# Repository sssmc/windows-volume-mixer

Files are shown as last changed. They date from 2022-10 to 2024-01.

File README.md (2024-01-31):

# Windows Volume Mixer

A physical hardware interface for adjusting main and per-app volumes in windows.



### Hardware

All hardware is presented in a desktop unit mounted at an angle for ergonomic use. The mixer consists of four channels. Each channel has a small screen for displaying the name of the channel, a rotary encoder knob for controlling the volume of that channel and ring of RGB LEDs around the knob to display the volume level of the channel. Below the knobs is a bank of key switches that can control aspects of the mixer as well other functions in windows. The mixer is connected to the windows PC via a USB-C cable for power and communications.

I2C is used for the screens, encoders, and buttons. All devices are connected to the microcontroller via cables and connectors, resulting minimal soldering needed for the construction. Once the initial soldering is completed, the whole unit can be assembled and disassembled with no soldering needed.
The enclosure for the electronics is 3D-printable on consumer printer and uses minimal M2/M3 hardware for assembly.

### Software

The software for the mixer consists of two main parts: firmware running on the microcontroller and a python script running on the PC. The two programs communicate via serial over a USB cable. The firmware reads the values of the rotary encoders and the various buttons and reports them when they change to the PC over serial. The python scripts then process these values, set appropriate volumes on the PC, decides what apps will be assigned to what channels etc. The script then sends values to be displayed on the screens and the LED rings back to the microcontroller.

The python script uses the Pycaw library to access the windows APIs to get and change app specific volumes.

## Current State of the Project and Development Plans

The project is a working, but early state. The software especially has some instability and many features to be implemented.

### Hardware

The electronics are mostly final state. Since the components were chosen to facilitate fast prototyping, the overall cost of them was fairly high. This could be improved by incorporating more custom built parts or moving most components to a single custom PCB. However, this would be impractical outside larger scale production so therefore unlikely in the near future for this project.

The current 3D-printed enclosure consists of a solid faceplate mounted on an open frame. A fully enclosed design could add more polish to the project.

### Software

Software/firmware is where most of the remaining work is to be done on the project. The firmware on the microcontroller is fairly complete and has no know bugs at this time. The python script running on the pc has a few know issues and quite a few features to be implemented.

#### Know issues:
<ul>
    <li>Intermittent crashes when switching audio outputs in windows.</li>
    <li>Intermittent loss of master volume control.</li>
    <li>Random script crashes.</li>
</ul>

#### Missing features:
<ul>
    <li>When volumes or mutes are changed in windows, update mixer automatically.</li>
    <li>When output source is changed in windows, update mixer automatically.</li>
    <li>Display more info about channels on screens.</li>
    <li>Add more functions to buttons, including changing audio output sources.</li>
    <li>Add more user feedback using button backlights.</li>
    <li>Run python script in background(in task bar).</li>
    <li>Add GUI to view connection status and adjust settings.</li>
</ul>

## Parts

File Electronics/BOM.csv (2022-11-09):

Part Name | Part No. | Manufacturer | Quantity | Source | Notes
0.96in I2C 128x64 OLED | Various | Various | 4 | https://www.aliexpress.com/item/32638662748.html
NeoPixel Ring - 16 x 5050 RGB LED | 1463 | Adafruit | 4 | https://www.adafruit.com/product/1463
Adafruit I2C Stemma QT Rotary Encoder Breakout | 4991 | Adafruit | 4 | https://www.adafruit.com/product/4991
NeoKey 1x4 QT I2C - Four Mechanical Key Switches | 4980 | Adafruit | 2 | https://www.adafruit.com/product/4980
Adafruit Feather RP2040 | 4884 | Adafruit | 1 | https://www.adafruit.com/product/4884
FeatherWing Proto | 2884 | Adafruit | 1 | https://www.adafruit.com/product/2884
Stacking Headers for Feather | 2830 | Adafruit | 1 | https://www.adafruit.com/product/2830
Cherry MX Compatiable Keyswitch | Various | Various | 8 | Various
Cherry MX Compatiable Keycap | Various | Various | 8 | Various
Qwiic/Stemma QT Cable - 50mm | Various | Various | 4 | Various
Qwiic/Stemma QT Cable - 100mm | Various | Various | 2 | Various
Qwiic Cable - Female Jumper (4-pin) | Various | Various | 1 | Various | Modified to add a second set of female headers(to connected to 2 OLEDs)
JST PH 2mm 4-Pin to Female Socket Cable - 200mm | 3950 | Adafruit | 1 | Various | Modified to add a second set of female headers(to connected to 2 OLEDs)
JST PH 4-Pin Socket | Various | Various | 1 | Various
JST PH 3-Pin Socket | Various | Various | 4 | Various
JSP PH 3-Pin Connector | Various | Various | 4 | Various
Single Female Header Jumper | Various | Various | 8 | Various | For OLED cable modifications
Misc. Hookup Wire | Various | Various |  | Various | For cable modifications and connections on feather wing proto
Misc. M3/M2 Machine Screws | Various | Various |  | Various

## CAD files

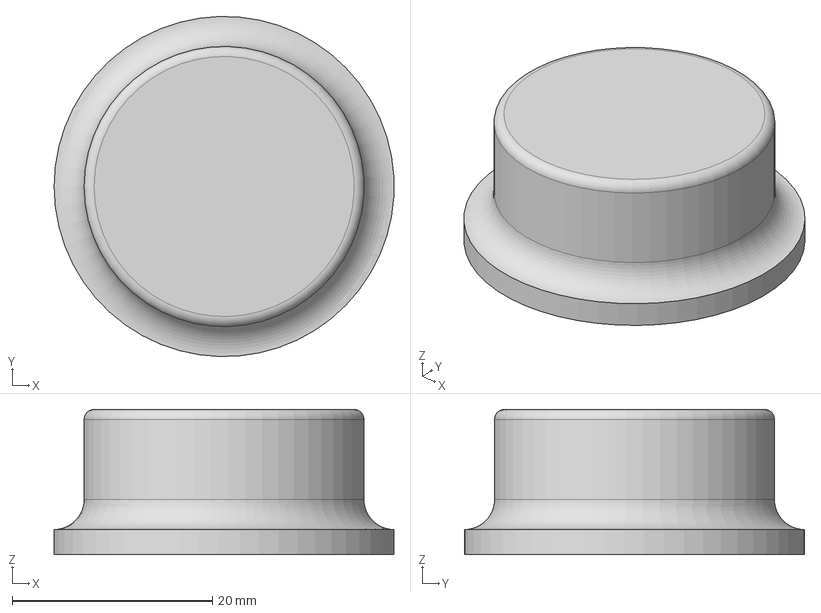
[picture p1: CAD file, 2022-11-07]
3D Models/Knob/Knob V1.step
34.0 x 34.0 x 14.5 mm

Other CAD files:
3D Models/Knob/Knob_V1.f3d
3D Models/Knob/Knob_V1.stl

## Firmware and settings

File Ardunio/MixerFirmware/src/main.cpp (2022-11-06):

#include <Arduino.h>

#include "Adafruit_NeoKey_1x4.h"
#include "seesaw_neopixel.h"
#include <Adafruit_NeoPixel.h>

#include <Adafruit_GFX.h>
#include <Adafruit_SSD1306.h>

//Pins for encoder seesaw chip
#define SS_SWITCH        24
#define SS_NEOPIX        6

//Max brightness for the neopixel rings
#define RING_BRIGHTNESS 25.5

//OLED screens
#define SCREEN_WIDTH 128 // OLED display width, in pixels
#define SCREEN_HEIGHT 32 // OLED display height, in pixels
#define OLED_RESET     -1 // Reset pin # (or -1 if sharing Arduino reset pin)

//I2C Buses and pins(Wire1 = Stemma Qt connector, Wire = feather wing)
#define WIRE Wire
#define WIRE1 Wire1
#define WIRE_SDA 8
#define WIRE_SCL 9
#define WIRE1_SDA 2
#define WIRE1_SCL 3

//Serial Baud Rate
#define SERIAL_BAUD_RATE 4000000

#define SLEEP_DELAY 6000

int inputCount = 0;

//I2C addresses
int rotary_addrs[4] = {0x36, 0x37, 0x3A, 0x38};
int key_addrs[2] = {0x30, 0x31};
int display_addrs[4] = {0x3C, 0x3D, 0x3C, 0x3D};

//Order to turn on the pixels in the neopixel rings
int ring_pixel_order[16] = {5, 4, 3, 2, 1, 0, 15, 14, 13, 12, 11, 10, 9, 8, 7, 6};

//input data from the serial bus(20 char arrays, max 255 chars each)
char inData[20][255];

//OLED display objects
Adafruit_SSD1306 displays[] = {
  Adafruit_SSD1306(SCREEN_WIDTH, SCREEN_HEIGHT, &Wire1, OLED_RESET),
  Adafruit_SSD1306(SCREEN_WIDTH, SCREEN_HEIGHT, &Wire1, OLED_RESET),
  Adafruit_SSD1306(SCREEN_WIDTH, SCREEN_HEIGHT, &Wire, OLED_RESET),
  Adafruit_SSD1306(SCREEN_WIDTH, SCREEN_HEIGHT, &Wire, OLED_RESET)
};

//Neo Key objects
Adafruit_NeoKey_1x4 keys[] = {
  Adafruit_NeoKey_1x4('0', &Wire1),
  Adafruit_NeoKey_1x4('0', &Wire1),
};

//Encoder objects
Adafruit_seesaw encoders[4] = {
  Adafruit_seesaw(&Wire1),
  Adafruit_seesaw(&Wire1),
  Adafruit_seesaw(&Wire1),
  Adafruit_seesaw(&Wire1)
};

//Neopixel ring objects(with pins)
Adafruit_NeoPixel rings[4] = {
  Adafruit_NeoPixel(16, A0, NEO_GRB + NEO_KHZ800),
  Adafruit_NeoPixel(16, A1, NEO_GRB + NEO_KHZ800),
  Adafruit_NeoPixel(16, A2, NEO_GRB + NEO_KHZ800),
  Adafruit_NeoPixel(16, A3, NEO_GRB + NEO_KHZ800)
};

//Encoder postion vars
int32_t encoder_positions[] = {0, 0, 0, 0};
int32_t encoder_last_positions[] = {0, 0, 0, 0};
int32_t encoder_position_changes[] = {0, 0, 0, 0};

//Encoder button vars
bool encoder_button_states[] = {false, false, false, false};
bool encoder_button_last_states[] = {false, false, false, false};

//Neokey button state vars
bool button_states[] = {false, false, false, false, false, false, false, false};
bool button_last_states[] = {false, false, false, false, false, false, false, false};

//Colors of the neokey button backlights(hex)
int buttonColors[8] = {0x0000FF, 0x0000FF, 0x0000FF, 0x0000FF, 0x0000FF, 0x0000FF, 0x0000FF, 0x0000FF};

//Neopixel ring levels(0-16)
int ring_levels[4] = {0, 0, 0, 0};

//Color of the neopixel rings(hex)
int ringColors[4] = {0xFF8000, 0xFF8000, 0xFF8000, 0xFF8000};

//No connection neopixel ring color
int NO_CONNECT_COLOR = 0x0000FF;

//No connection display text
String NO_CONNECTION_TEXT = "No Connection";

//OLED display texts
char appNames[4][255];

//Is it the first time going thorugh the loop since the serial was connected
bool serialFirstTime = true;

//Sleep Timer
unsigned long sleepTimerStart = 0;


//--Function Prototypes--//

//Write the data to serial
//Formate: [(encoder positon changes)x4, (neokey button states)x8, (encoder button states)x4]
void serialWrite();

//Read data from serial
void serialRead();

//Get the neokey button states and update the neopixle backlight colors
void getKeys();

//Get encoder position and button data
void getEncoders();

//Set the level and color of the neopixel rings
void setRings();

//Set the text for the OLED displays
void setDisplays();

//Set neopixel rings to the no connection color and set a no connection message on the first screen
//Option so clear all displays
void setNoConnection(bool clearDisplay);

//Puts device in sleep mode
void setSleep();


void setup() {

  //Setup and start the I2C busses
  WIRE.setSDA(WIRE_SDA);
  WIRE.setSCL(WIRE_SCL);
  WIRE.begin();

  WIRE1.setSDA(WIRE1_SDA);
  WIRE1.setSCL(WIRE1_SCL);
  WIRE1.begin();

  //Start the OLED displays
  for (int i = 0; i < 4; i++) {
    if (!displays[i].begin(SSD1306_SWITCHCAPVCC, display_addrs[i])) {
      for (;;); // Can't start display, don't proceed, loop forever
    }
    displays[i].display();//Show the default splash screen
  }

  //Start the neokeys
  for (int i = 0; i < 2; i ++) {
    if (! keys[i].begin(key_addrs[i])) {
      while (1) delay(10);
    }
  }
  
  //Start the endoders
  for (int i = 0; i < 4; i++) {

    Adafruit_seesaw ss = encoders[i];

    if (! ss.begin(rotary_addrs[i])) {
      while (1) delay(10); //Can't start, loop forever
    }
    uint32_t version = ((ss.getVersion() >> 16) & 0xFFFF);
    if (version  != 4991) {
      while (1) delay(10); //Incorrect seesaw firware version, loop forever
    }
    encoders[i] = ss;

    //Set intial positions for the encoders
    encoder_positions[i] = encoders[i].getEncoderPosition();
    encoder_button_states[i] = encoders[i].digitalRead(SS_SWITCH);
    encoder_button_last_states[i] = encoders[i].digitalRead(SS_SWITCH);
  }

  //Start the neopixel rings
  for (int i = 0; i < 4; i++) {
    rings[i].begin();

    //Set max brightness
    rings[i].setBrightness(RING_BRIGHTNESS);
  }

  //Show a no connection message on the first screen and set rings to no connection color
  setNoConnection(false);

  //Start the serial connection and wait until the pc connect before proceding
  Serial.begin(SERIAL_BAUD_RATE);

  sleepTimerStart = millis();

}

void loop() {
  
  //If the pc is connected to the serial

  //Neokeys
  getKeys();

  //Encoders
  getEncoders();
  if (Serial) {
    //If there is the first loop since the serial was connected, sent data to get a respose from the pc
    if (serialFirstTime) {
      serialWrite();
      serialFirstTime = false;
    }

    sleepTimerStart = millis();//Restart sleep timer(since the device does not sleep when connected to serial)

    //While they are bytes in the serial buffer, read data and set rings/displays
    while (Serial.available() > 0) {

        serialRead();
    }

  }else
  {
    //If there is no serial connection, set ring and displays to no connection state

    serialFirstTime = true;

    //If the sleep timer triggers(the serial connection has been lost for the sleep delay or more)
    if((millis() - sleepTimerStart) > SLEEP_DELAY){

      setSleep();

    } else{
      setNoConnection(true);
    }

  }
}

void serialWrite() {
  sleepTimerStart = millis();//Restart sleep timer(since a user changed an input)
  if(Serial){
    Serial.print("[");

    for (int i = 0; i < 4; i++) {
      Serial.print(encoder_position_changes[i]);
      Serial.print(",");
    }

    for (int i = 0; i < 8; i++) {
      Serial.print(button_states[i]);
      Serial.print(",");
    };
    for (int i = 0; i < 4; i++) {
      Serial.print(!encoder_button_states[i]);
      Serial.print(",");
    }
    Serial.println("]");
  }
}

void getKeys(){
  for (int i = 0; i < 2; i++) {
      Adafruit_NeoKey_1x4 neokey = keys[i];
      uint8_t buttons = neokey.read();

      // Check each button. Ff the state has changed since last check, write to serial
      if (buttons & (1 << 0)) {
        if (!button_states[4 * i]) {
          button_states[4 * i] = true;
          serialWrite();
        }
      } else {
        if (button_states[4 * i]) {
          button_states[4 * i] = false;
          serialWrite();
        }
      }
      if (buttons & (1 << 1)) {
        if (!button_states[(4 * i) + 1]) {
          button_states[(4 * i) + 1] = true;
          serialWrite();
        }
      } else {
        if (button_states[(4 * i) + 1]) {
          button_states[(4 * i) + 1] = false;
          serialWrite();
        }
      }
      if (buttons & (1 << 2)) {
        if (!button_states[(4 * i) + 2]) {
          button_states[(4 * i) + 2] = true;
          serialWrite();
        }
      } else {
        if (button_states[(4 * i) + 2]) {
          button_states[(4 * i) + 2] = false;
          serialWrite();
        }
      }
      if (buttons & (1 << 3)) {
        if (!button_states[(4 * i) + 3]) {
          button_states[(4 * i) + 3] = true;
          serialWrite();
        }
      } else {
        if (button_states[(4 * i) + 3]) {
          button_states[(4 * i) + 3] = false;
          serialWrite();
        }
      }
      //Set the button backlight neopixel colors
      for(int b = 0;b < 4; b++){
        neokey.pixels.setPixelColor(b, buttonColors[(4 * i) + b]);
      }
      neokey.pixels.show();
    }
}

void getEncoders(){
  for (int i = 0; i < 4; i++) {
      //Get encoder positons and button states
      encoder_positions[i] = encoders[i].getEncoderPosition();
      encoder_button_states[i] = encoders[i].digitalRead(SS_SWITCH);

      //If the encoder positon has chages since the last check, calculate the position diffrence since last check and write to serial
      if (encoder_positions[i] != encoder_last_positions[i]) {
        encoder_position_changes[i] = encoder_positions[i] - encoder_last_positions[i];
        serialWrite();
        //Reset last position
        encoder_last_positions[i] = encoder_positions[i];
      } else {
        //If there has been no change, set position difference to 0
        encoder_position_changes[i] = 0;
      }

      //If the encoder button has changed since last check, update state and write to serial
      if (encoder_button_states[i] != encoder_button_last_states[i]) {
        serialWrite();
        encoder_button_last_states[i] = encoder_button_states[i];
      }
    }
}

void setDisplays(){

  //Set each display to its app name
  for (int i = 0; i < 4; i ++) {
    displays[i].clearDisplay();
    displays[i].setTextSize(2);
    displays[i].setTextColor(SSD1306_WHITE);
    displays[i].setCursor(0, 0);
    displays[i].println(String(appNames[i]));
    displays[i].display();
  }

}

void setRings(){

  for (int i = 0; i < 4; i++)
    {
      //Clear the ring
      rings[i].clear();

      //Set the number of pixels lit on the ring base on the ring level(0-16)
      for (int r = 0; r < ring_levels[i]; r++) {
        //Use the the custom pixel order to choose the order that the pixels are turned on
        //Use the ring color of that ring to dertimin the color
        rings[i].setPixelColor(ring_pixel_order[r], ringColors[i]);
      }
      //Show the pixels
      rings[i].show();
    }

}

void serialRead(){

  sleepTimerStart = millis();

  //Read string until a comma is reached(end of value), String is then converted into char array and added to in data array
  Serial.readStringUntil(',').toCharArray(inData[inputCount], 255);

  //Keep track of how many values have been read on the current line
  inputCount ++;

  //If we have reached the end of the line(empty string caused by the ",," at the end of the line), process line
  if (String(inData[inputCount - 1]) == "") {

    //Reset line value count
    inputCount = 0;
    int displayCount = 0;

    //Read ring and button colors(as ints)
    for (int i = 0; i < 4; i++) {
      ringColors[i] = String(inData[i + 8]).toInt();
    }
    for (int i = 0; i < 8; i++) {
      buttonColors[i] = String(inData[i + 12]).toInt();
    }

    //Read the display text to app name array
    for (int i = 0; i <= 6; i += 2) {
      String(inData[i]).toCharArray(appNames[displayCount],255);
      displayCount ++;

    }
    int ringCount = 0;
    for (int i = 1; i <= 7; i += 2)
    {
      ring_levels[ringCount] = String(inData[i]).toInt();
      ringCount++;

    }

    setDisplays();

    setRings();

  }
}

void setNoConnection(bool clearDisplay){

  //Clear right three displays if needed
  if(clearDisplay){
    for(int i = 1; i < 4; i++){
      displays[i].clearDisplay();
      displays[i].display();
    }
  }

  //Add no connection text to the first display
  displays[0].clearDisplay();
  displays[0].setTextColor(SSD1306_WHITE);
  displays[0].setCursor(0, 0);
  displays[0].setTextSize(1);
  displays[0].print(NO_CONNECTION_TEXT);
  displays[0].display();

  //Set the neopixel rings to the no connection color
  for (int i = 0; i < 4; i++) {
      rings[i].fill(NO_CONNECT_COLOR);
      rings[i].show();
  }

  //Set button backlights to no connection colors
  for(int i = 0; i < 8; i++){
        buttonColors[i] = NO_CONNECT_COLOR;
  }
  

}

void setSleep(){

  //Clear all displayes and rings
  for(int i = 0; i < 4; i++){
    displays[i].clearDisplay();
    displays[i].display();
    rings[i].fill(0);
    rings[i].show();
  }
  //Turn off all button backlights
  for(int i = 0; i < 8; i++){
    buttonColors[i] = 0;
  }

}

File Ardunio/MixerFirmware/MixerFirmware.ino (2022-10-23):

#include "Adafruit_NeoKey_1x4.h"
#include "seesaw_neopixel.h"
#include <Adafruit_NeoPixel.h>

#include <Adafruit_GFX.h>
#include <Adafruit_SSD1306.h>

#define SS_SWITCH        24
#define SS_NEOPIX        6

#define RING_BRIGHTNESS 25.5

#define SCREEN_WIDTH 128 // OLED display width, in pixels
#define SCREEN_HEIGHT 32 // OLED display height, in pixels
#define OLED_RESET     -1 // Reset pin # (or -1 if sharing Arduino reset pin)

#define WIRE Wire
#define WIRE_SDA 8
#define WIRE_SCL 9

int rotary_addrs[4] = {0x36, 0x37, 0x3A, 0x38};
int key_addrs[2] = {0x30, 0x31};
int display_addrs[4] = {0x3C, 0x3D, 0x3C, 0x3D};

int ring_pixel_order[16] = {5, 4, 3, 2, 1, 0, 15, 14, 13, 12, 11, 10, 9, 8, 7, 6};

char inData[20][255];

String inString = "";

int inputCount = 0;

Adafruit_SSD1306 displays[] = {
  Adafruit_SSD1306(SCREEN_WIDTH, SCREEN_HEIGHT, &Wire1, OLED_RESET),
  Adafruit_SSD1306(SCREEN_WIDTH, SCREEN_HEIGHT, &Wire1, OLED_RESET),
  Adafruit_SSD1306(SCREEN_WIDTH, SCREEN_HEIGHT, &Wire, OLED_RESET),
  Adafruit_SSD1306(SCREEN_WIDTH, SCREEN_HEIGHT, &Wire, OLED_RESET)
};


Adafruit_NeoKey_1x4 keys[] = {
  Adafruit_NeoKey_1x4('0', &Wire1),
  Adafruit_NeoKey_1x4('0', &Wire1),
};

// create 4 encoders!
Adafruit_seesaw encoders[4] = {
  Adafruit_seesaw(&Wire1),
  Adafruit_seesaw(&Wire1),
  Adafruit_seesaw(&Wire1),
  Adafruit_seesaw(&Wire1)
};
// create 4 encoder pixels
seesaw_NeoPixel encoder_pixels[4] = {
  seesaw_NeoPixel(1, SS_NEOPIX, NEO_GRB + NEO_KHZ800, &Wire1),
  seesaw_NeoPixel(1, SS_NEOPIX, NEO_GRB + NEO_KHZ800, &Wire1),
  seesaw_NeoPixel(1, SS_NEOPIX, NEO_GRB + NEO_KHZ800, &Wire1),
  seesaw_NeoPixel(1, SS_NEOPIX, NEO_GRB + NEO_KHZ800, &Wire1)
};

Adafruit_NeoPixel rings[4] = {
  Adafruit_NeoPixel(16, A0, NEO_GRB + NEO_KHZ800),
  Adafruit_NeoPixel(16, A1, NEO_GRB + NEO_KHZ800),
  Adafruit_NeoPixel(16, A2, NEO_GRB + NEO_KHZ800),
  Adafruit_NeoPixel(16, A3, NEO_GRB + NEO_KHZ800)
};


int32_t encoder_positions[] = {0, 0, 0, 0};
int32_t encoder_last_positions[] = {0, 0, 0, 0};
int32_t encoder_position_changes[] = {0, 0, 0, 0};
bool button_states[] = {false, false, false, false, false, false, false, false};
bool button_last_states[] = {false, false, false, false, false, false, false, false};
bool encoder_button_states[] = {false, false, false, false};
bool encoder_button_last_states[] = {false, false, false, false};

int ring_levels[4] = {0, 0, 0, 0};
String app_names[4] = {"none", "none", "none", "none"};

long ringColors[4] = {0xFF8000, 0xFF8000, 0xFF8000, 0xFF8000};
long buttonColors[8] = {0xFF8000, 0x0026FF, 0xFF8000, 0x0026FF, 0xFF8000, 0x0026FF, 0xFF8000, 0x0026FF};

bool serialFirstTime = true;

void serialWrite() {
  Serial.print("[");

  for (int i = 0; i < 4; i++) {
    Serial.print(encoder_position_changes[i]);
    Serial.print(",");
  }

  for (int i = 0; i < 8; i++) {
    Serial.print(button_states[i]);
    Serial.print(",");
  };
  for (int i = 0; i < 4; i++) {
    Serial.print(!encoder_button_states[i]);
    Serial.print(",");
  }
  Serial.println("]");
};



void setup() {

  WIRE.setSDA(WIRE_SDA);
  WIRE.setSCL(WIRE_SCL);
  WIRE.begin();

  pinMode(LED_BUILTIN, OUTPUT);

  for (int i = 0; i < 4; i++) {
    // SSD1306_SWITCHCAPVCC = generate display voltage from 3.3V internally
    if (!displays[i].begin(SSD1306_SWITCHCAPVCC, display_addrs[i])) {
      //Serial.println(F("SSD1306 allocation failed"));
      for (;;); // Don't proceed, loop forever
    }
    displays[i].display();
    delay(500);
    displays[i].clearDisplay();
    displays[i].setTextSize(2);
    displays[i].setTextColor(SSD1306_WHITE);
    displays[i].setCursor(0, 0);
    displays[i].println("Display: " + String(i) + " @ " + String(display_addrs[i]));
    displays[i].display();

  }
  delay(500);

  for (int i = 0; i < 2; i ++) {
    //Serial.println("Starting NeoKey @ " + String(key_addrs[i]));
    if (! keys[i].begin(key_addrs[i])) {     // begin with I2C address, default is 0x30
      //Serial.println("Could not start NeoKey @ " + String(key_addrs[i]) + " , check wiring?");
      while (1) delay(10);
    }
    //Serial.println("Started NeoKey @ " + String(key_addrs[i]));
  }
  for (int i = 0; i < 4; i++) {

    Adafruit_seesaw ss = encoders[i];
    seesaw_NeoPixel sspixel = encoder_pixels[i];

    if (! ss.begin(rotary_addrs[i]) || ! sspixel.begin(rotary_addrs[i])) {
      //Serial.println("Couldn't find seesaw on: " + String(rotary_addrs[i]));
      while (1) delay(10);
    }
    //Serial.println("seesaw started on: " + String(rotary_addrs[i]));

    uint32_t version = ((ss.getVersion() >> 16) & 0xFFFF);
    if (version  != 4991) {
      //Serial.print("Wrong firmware loaded? ");
      //Serial.println(version);
      while (1) delay(10);
    }
    ///Serial.println("Found Product 4991");

    // set not so bright!
    sspixel.setBrightness(20);
    sspixel.show();

    encoders[i] = ss;
    encoder_pixels[i] = sspixel;

    encoder_positions[i] = encoders[i].getEncoderPosition();
  }

  for (int i = 0; i < 4; i++) {
    rings[i].begin();           // INITIALIZE NeoPixel strip object (REQUIRED)
    rings[i].setBrightness(RING_BRIGHTNESS); // Set BRIGHTNESS to about 1/5 (max = 255)
    rings[i].fill(rings[i].Color(0,   0,   255));
    rings[i].show();            // Turn OFF all pixels ASAP
  }

  for (int i = 0; i < 4; i++) {
    displays[i].clearDisplay();
    displays[i].display();
  }
  displays[0].setCursor(0, 0);
  displays[0].setTextSize(1);
  displays[0].print("No Connection");
  displays[0].display();

  Serial.begin(9600);
  while (! Serial) delay(10);
}
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

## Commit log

2022-10-23 encoder button support in firmware
2022-10-23 add ring and button color support over serial in firmware
2022-10-23 encoder button mute support with ring colors in windows CLI
2022-10-23 basic button backlight suppot in windows CLI
2022-10-24 mute fixes and temp api error handeling
    [windowsCommandLine.py]
2022-10-29 fritzing drawing of hardware mixer
    [windows_volume_mixer.fzz]
2022-10-30 set encoder button inital states in setup
2022-11-06 add device sleep support when not connected to serial
2022-11-07 add encoder knob model
    [Knob V1.step, Knob_V1.f3d, Knob_V1.stl]
2022-11-09 Add BOM
    [BOM.csv]
